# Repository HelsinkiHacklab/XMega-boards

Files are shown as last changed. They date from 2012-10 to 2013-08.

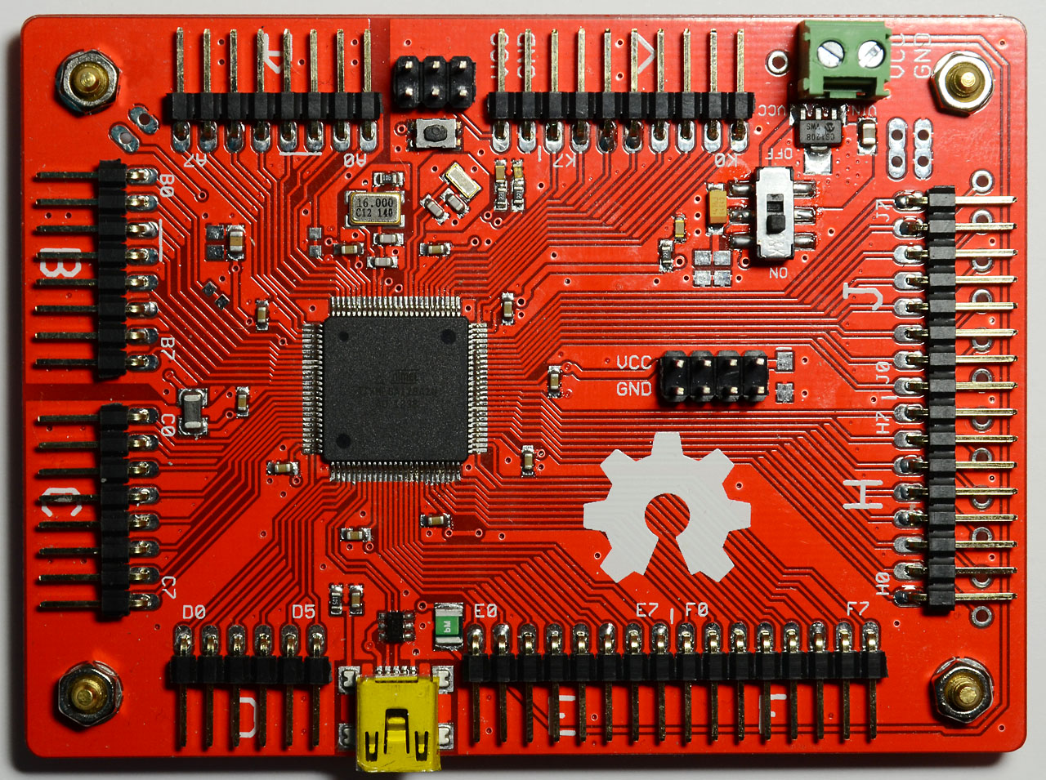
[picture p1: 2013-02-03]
XmegaA1U_v1.jpg

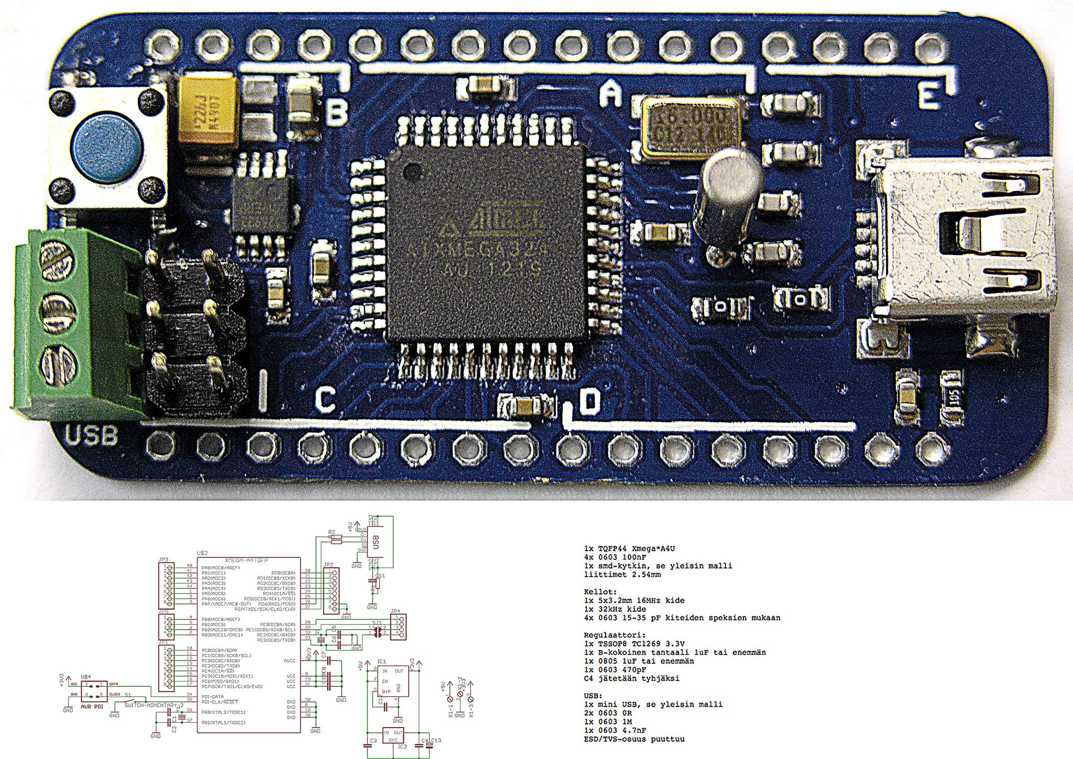
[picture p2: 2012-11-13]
XmegaA4U_v1.jpg

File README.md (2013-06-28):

XMega-boards
============

Breakouts for various XMegas with required supporting hardware

## Boards

  - XmegaA4U_v1: XMEGA A4U, TSSOP-8 regulator (TO-92 as an option), mini USB, 30 i/o pins.
    The first test board, works fine but the regulator used
    is no longer stocked by digikey/mouser. You can still use a TO-92 
    regulator though.
  - XmegaA4U_v2.0: XMEGA A4U, SOT-89 regulator, mini USB, 30 i/o pins.
    A slightly revised edition of v1. USB resistors removed, one LED added and regulator changed.
  - XmegaA4U_v2.1: XMEGA A4U, TSSOP-8 regulator, micro USB, 20 i/o pins.
    A smaller version with fewer pins and a split ground plane. Supports minimal 
    AVCC and AREF filtering. USB connector changed, reset button and 
    separate power connector removed.
  - XmegaA4U_v2.3: XMEGA A4U, SOT-89 regulator, micro USB, 30 i/o pins.
    Version with micro USB, some additional vcc/gnd pins and possibility to 
    add leds to pins E2 and E3.

## Software

For example Arduino IDE (well, XMegaduino) pin definitions for these boards (or at least some of them).

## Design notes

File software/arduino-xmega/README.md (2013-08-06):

# Arduino-XMega patches

1. Get the base software from https://github.com/akafugu/Xmegaduino
2. Under the installation directory in `hardware/xmegaduino/variants` symlink/copy the directories from the variants directory in this repo
3. Under the installation directory in `hardware/xmegaduino/` to `board.txt` add (to end of file) the contents of `add_to_boards.txt`

I (rambo) [updated](https://github.com/rambo/arduino-tiny/tree/attiny1634/avr-gcc) the AVR toolchain but I'm not 100% it's required.

## More detailed instructions

1. Download correct package for your platform from [download page](https://github.com/akafugu/Xmegaduino/downloads) (MacOS, Linux or Windows)
2. Extract the package
3. Get this project by checking it out from GitHub with `git clone https://github.com/HelsinkiHacklab/XMega-boards.git`
4. Copy or link `hhl_xmega32_v1_pdi` from `XMega-boards/software/arduino-xmega/variants/` under `hardware/xmegaduino/variants` in the directory you extracted from package in step 2.
5. Add text from `add_to_boards.txt` in `boards.txt` file in `hardware/xmegaduino`
6. Depending on your platform, the `hardware` directory may be in different places
    * On Windows and Linux package extracts into directory called `arduino`and `hardware` is a subdirectory under it.
    * On MacOS package extracts into Arduino.App application bundle and `hardware` is inside it under `Contents/Resources/Java`. You can either Ctrl-click on Finder and select "Show package contents". On commandline the application bundle shows as a regular directory.
7. If you don't have git (Windows), you can either download the repository as zipfile from repository's front page or use "raw" button to get individual files. If you do latter, remember to create `hhl_xmega32_v1_pdi` directory and put `pins_arduino.h` and `serial_init.cpp` in there.

## TODO

Instructions on how to make Arduino IDE to keep the hex-file (and how to find it) so you can use dfu_programmer in case you have no PDI-capable programmer handy

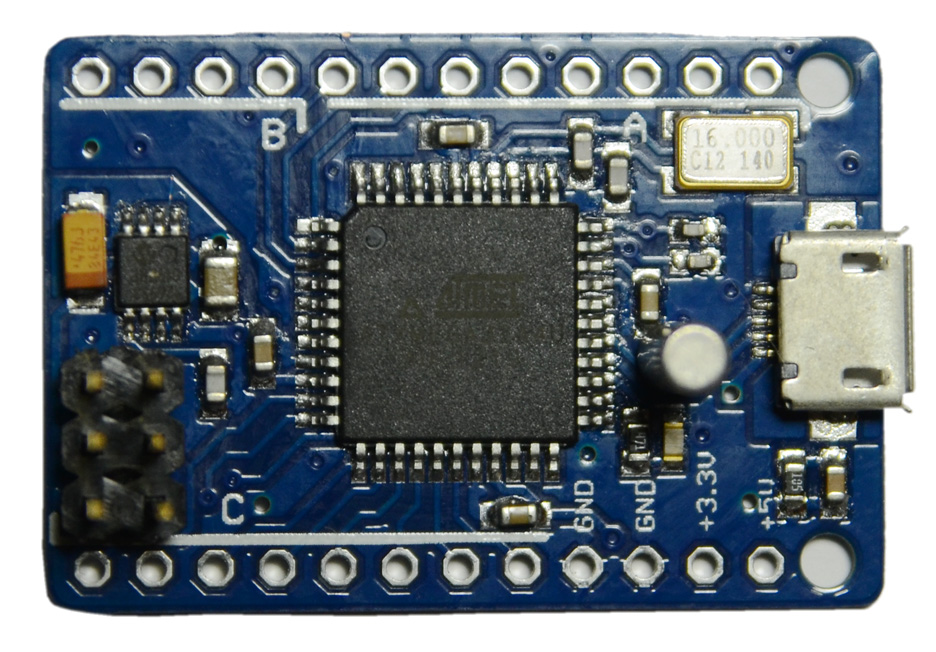
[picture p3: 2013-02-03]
XmegaA4U_v2.1.jpg

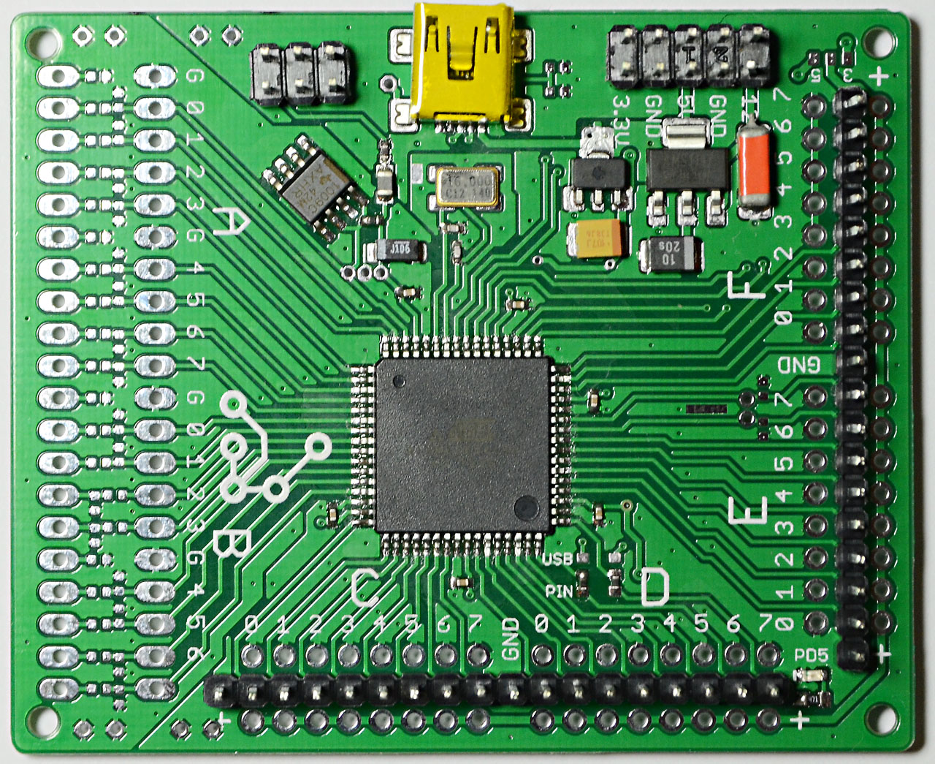
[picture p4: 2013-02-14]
XmegaA3U_v1.jpg

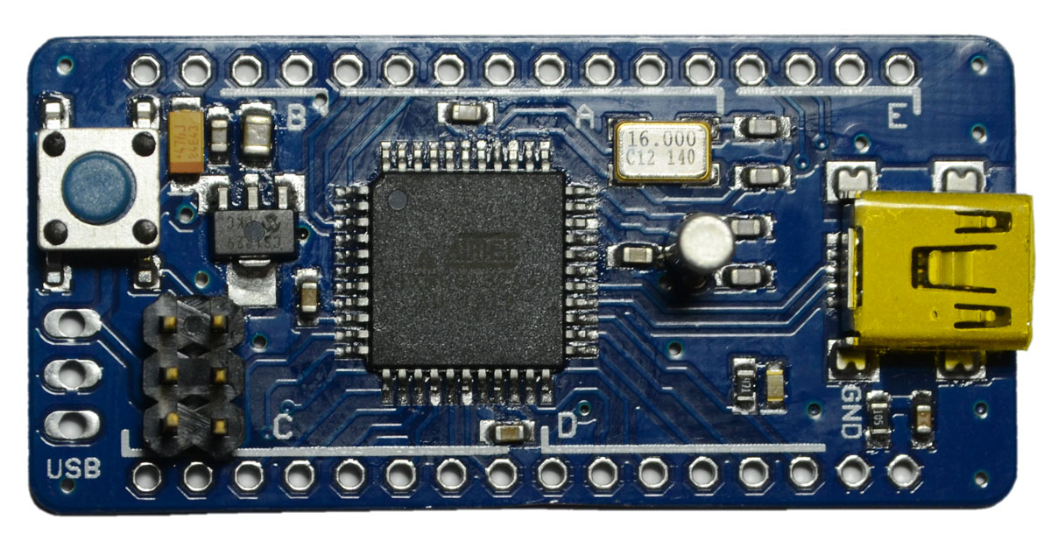
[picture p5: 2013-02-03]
XmegaA4U_v2.0.jpg

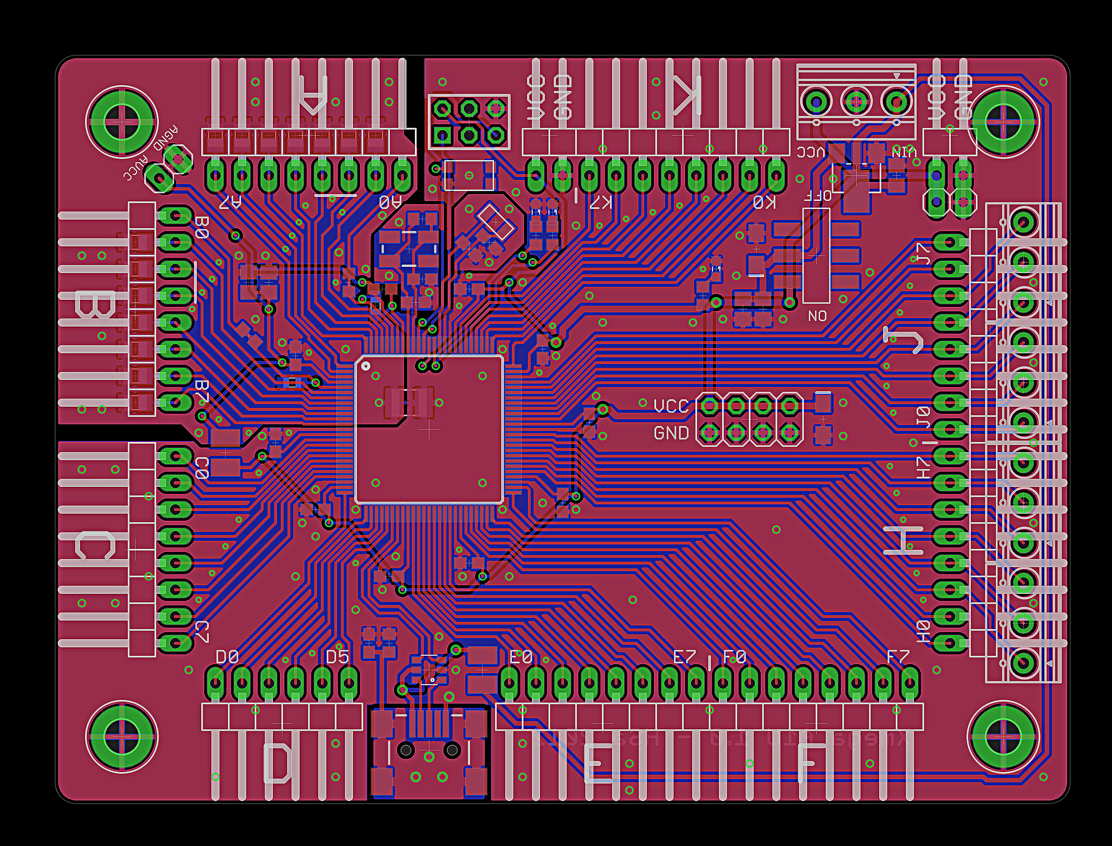
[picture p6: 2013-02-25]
XmegaA1U_v1_art.jpg

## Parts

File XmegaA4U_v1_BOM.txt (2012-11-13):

Kontrolleri Xmega32A4U

Alkuperäisen suunnitelman mukainen komponenttilista:
IC1: Microchip TC1269 3.3V
U$1: Mini USB B /w board guide, se yleisin malli
S1: SMD-painonappi, se yleisin malli 
Y1: 5.0x3.2 mm kide 
Q1: TH 32 kHz kide

Ja ohjearvoja, valmistajien mukaan:
C1-2, C5-6: 0603 konkat kiteiden speksien mukaan
C3: 0805 1 uF tai yli
C4: Jätetään tyhjäksi
C7-10: 0603 100 nF
C11: 0603 4.7 nF (tai jätetään tyhjäksi)
C12: 0603 470 pF tai jätetään tyhjäksi
C13: Tantaali B-case 1 uF tai mielellään yli
R1: 0603 noin 1M (tai 0R tai jätetään tyhjäksi)
R2-3: 0603 0R (tai 10-22R)

Suluissa olevat vaihtoehdot vaihtoehtoisista lähteistä (ei valmistajan suositus). Piirin nurjalla puolella on jumpperit, joilla toisen kellokiteen tilalle saa kaksi io-pinniä. R2 ja R3 toimivat USB:n datan jumppereina.

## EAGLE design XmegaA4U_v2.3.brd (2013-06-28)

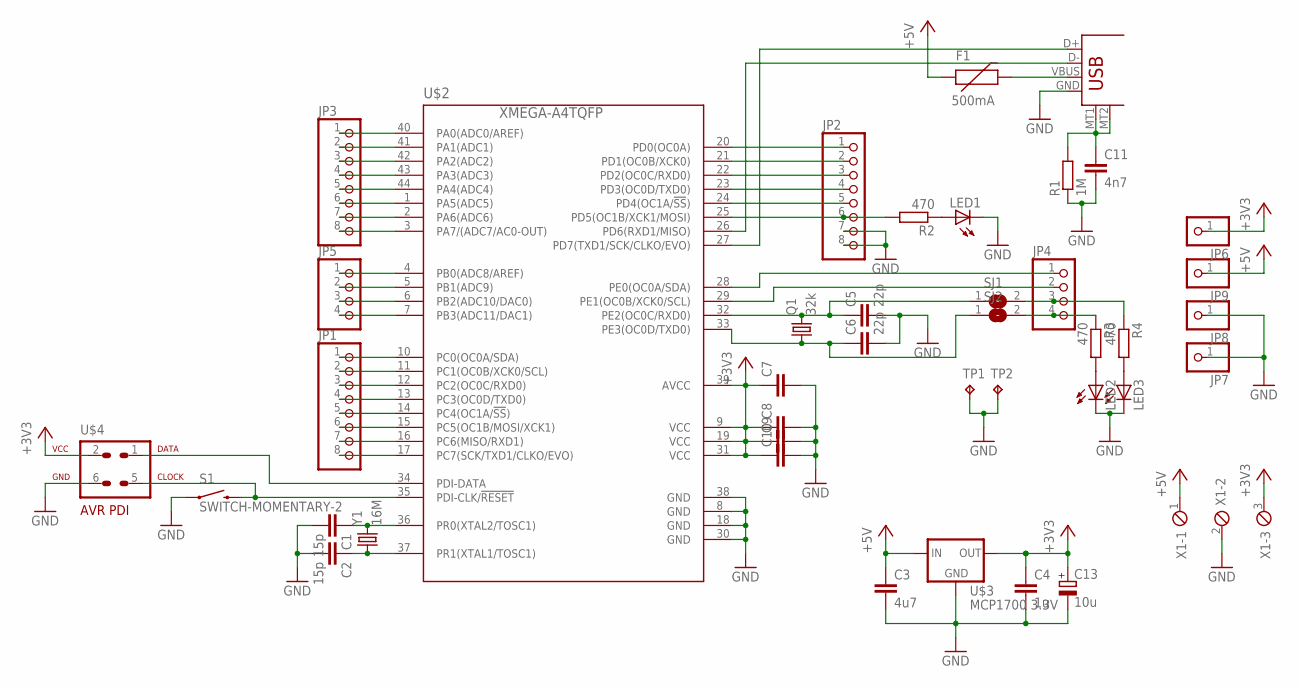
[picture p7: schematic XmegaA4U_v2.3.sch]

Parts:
C1, C2: 15p; C0603
C3: 4u7; C0805
C4: 1u; C0603
C5, C6: 22p; C0603
C7, C8, C9, C10: C-EUC0603; C0603
C11: 4n7; C0603
C13: 10u; SMC_A
F1: 500mA; 0805
JP1, JP2, JP3: PINHD_FIXEDPAD_ROUND-1X8; 1X08_ROUND
JP4, JP5: PINHD_FIXEDPAD_ROUND-1X4; 1X04_ROUND
JP6, JP7, JP8, JP9: PINHD_FIXEDPAD_ROUND-1X1; 1X01_ROUND
LED1, LED2, LED3: LEDCHIP-LED0603; CHIP-LED0603
Q1: 32k; TC26V_1.27
R1: 1M; R0603
R2, R3, R4: 470; R0603
S1: SWITCH-MOMENTARY-2; TACTILE_SWITCH_TALL
SJ1, SJ2: SJ_SMALL; SJ_2S-NO
TP1, TP2: TPTP15R; TP15R
U$2: XMEGA-A4TQFP; TQFP44
U$3: MCP1700 3.3V; SOT89-W
U$4: AVR-PDIVERT; AVR-ISP-6
U$5: USB+SHIELDMICRO; USB-MICROB
X1: MPT3; 3POL254
Y1: 16M; CRYSTAL-SMD-5X3

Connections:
+3V3: C4.1, C7.1, C8.1, C9.1, C10.1, C13.+, JP6.1, U$2.9 (VCC), U$2.19 (VCC), U$2.31 (VCC), U$2.39 (AVCC), U$3.3 (OUT), U$4.2, X1.3
+5V: C3.1, F1.1, JP9.1, U$3.2 (IN), U$3.TAB (IN), X1.1
GND: C1.2, C2.2, C3.2, C4.2, C5.2, C6.2, C7.2, C8.2, C9.2, C10.2, C11.2, C13.-, JP2.7, JP2.8, JP7.1, JP8.1, LED1.C, LED2.C, LED3.C, R1.1, S1.A2 (1), TP1.TP, TP2.TP, U$2.8 (GND), U$2.18 (GND), U$2.30 (GND), U$2.38 (GND), U$3.1 (GND), U$4.6, U$5.GND, X1.2
MTN: C11.1, R1.2, U$5.MT1, U$5.MT2
unnamed: C1.1, U$2.36 (PR0(XTAL2/TOSC1)), Y1.3 (2)
unnamed: C2.1, U$2.37 (PR1(XTAL1/TOSC1)), Y1.1
unnamed: F1.2, U$5.VBUS
unnamed: LED1.A, R2.1
unnamed: JP2.2, U$2.21 (PD1(OC0B/XCK0))
unnamed: JP2.3, U$2.22 (PD2(OC0C/RXD0))
unnamed: JP2.4, U$2.23 (PD3(OC0D/TXD0))
unnamed: JP2.5, U$2.24 (PD4(OC1A/!SS!))
unnamed: LED2.A, R3.2
unnamed: U$2.26 (PD6(RXD1/MISO)), U$5.D-
unnamed: LED3.A, R4.2
unnamed: JP3.2, U$2.41 (PA1(ADC1))
unnamed: JP3.3, U$2.42 (PA2(ADC2))
unnamed: JP3.4, U$2.43 (PA3(ADC3))
unnamed: JP3.5, U$2.44 (PA4(ADC4))
unnamed: JP3.6, U$2.1 (PA5(ADC5))
unnamed: JP3.7, U$2.2 (PA6(ADC6))
unnamed: JP1.2, U$2.11 (PC1(OC0B/XCK0/SCL))
unnamed: JP1.3, U$2.12 (PC2(OC0C/RXD0))
unnamed: JP1.4, U$2.13 (PC3(OC0D/TXD0))
unnamed: JP1.5, U$2.14 (PC4(OC1A/!SS!))
unnamed: JP1.6, U$2.15 (PC5(OC1B/MOSI/XCK1))
unnamed: JP1.7, U$2.16 (PC6(MISO/RXD1))
unnamed: JP5.2, U$2.5 (PB1(ADC9))
unnamed: JP5.3, U$2.6 (PB2(ADC10/DAC0))
unnamed: S1.B2 (2), U$2.35 (PDI-CLK/!RESET), U$4.5
unnamed: U$2.27 (PD7(TXD1/SCK/CLKO/EVO)), U$5.D+
unnamed: U$2.34 (PDI-DATA), U$4.1
XA0: JP3.1, U$2.40 (PA0(ADC0/AREF))
XA7: JP3.8, U$2.3 (PA7/(ADC7/AC0-OUT))
XB0: JP5.1, U$2.4 (PB0(ADC8/AREF))
XB3: JP5.4, U$2.7 (PB3(ADC11/DAC1))
XC0: JP1.1, U$2.10 (PC0(OC0A/SDA))
XC7: JP1.8, U$2.17 (PC7(SCK/TXD1/CLKO/EVO))
XD0: JP2.1, U$2.20 (PD0(OC0A))
XD5: JP2.6, R2.2, U$2.25 (PD5(OC1B/XCK1/MOSI))
XE0: JP4.1, U$2.28 (PE0(OC0A/SDA))
XE1: JP4.2, U$2.29 (PE1(OC0B/XCK0/SCL))
XE2: C5.1, Q1.2, SJ1.1, U$2.32 (PE2(OC0C/RXD0))
XE2S: JP4.3, R4.1, SJ1.2
XE3: C6.1, Q1.1, SJ2.1, U$2.33 (PE3(OC0D/TXD0))
XE3S: JP4.4, R3.1, SJ2.2

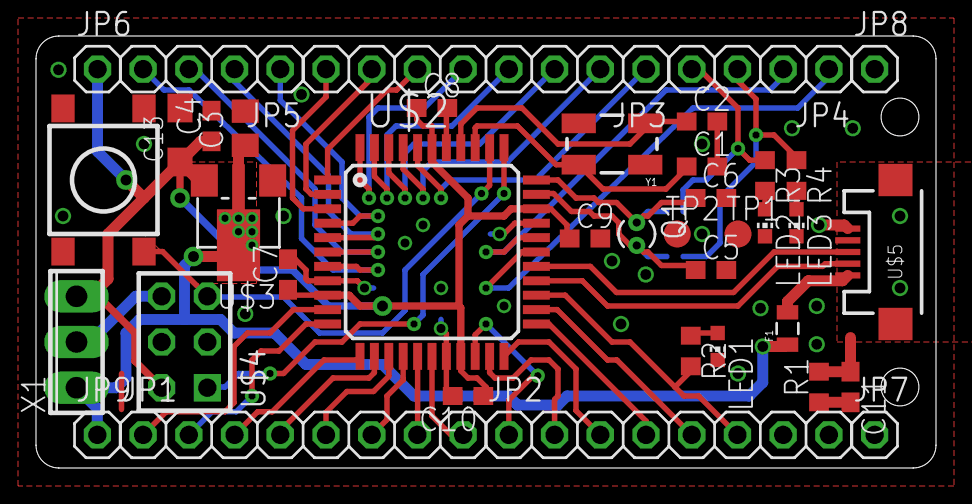
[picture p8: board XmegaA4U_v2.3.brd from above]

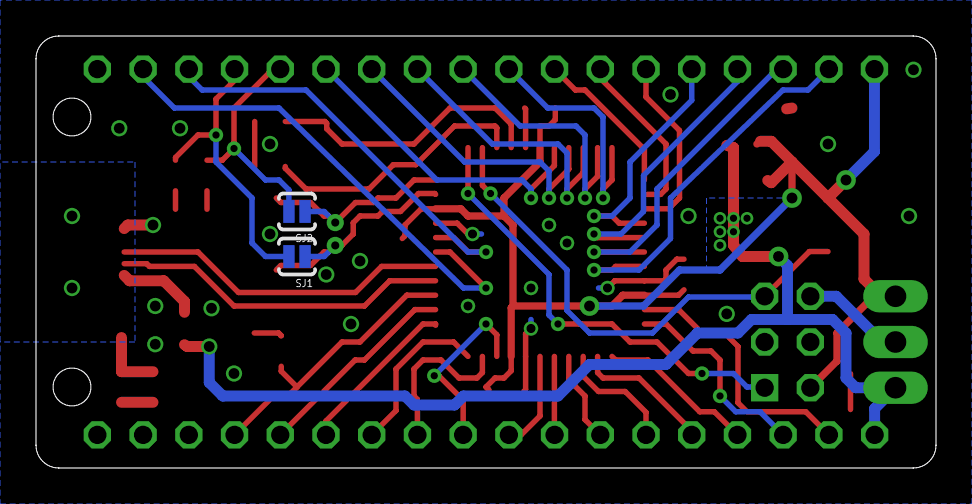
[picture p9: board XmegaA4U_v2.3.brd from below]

Board: 2 copper layers, 50.0 x 24.0 mm, 41 parts (2 on the bottom side), 46 nets.

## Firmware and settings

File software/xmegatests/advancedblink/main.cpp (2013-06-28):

// XMEGA 32AU4 Test 1 - Advanced LED blinking on PD5 with clocks:
//
//  - clkCPU/PER = 2 x external 16 MHz crystal oscillator = 32 MHz 
//  - clkPER4 = 4 x clkPER = 128 MHz hi-res clock
// 	- hi-res clock routed to PD4! Don't leave tangling jumpper wire on this pin, because it will act as an antenna!
//  - timer E0 used as system tick counter
//
// This code is demonstration purposes only, do not use in production code!
//
// References are to Atmel's documents:
//  - [AU] = doc8331.pdf, XMEGA AU Manual
//  - [A4U] = doc8387.pdf, ATxmega*A4U Datasheet
// 

#include <stddef.h>					// offsetof(…)

#include <avr/eeprom.h>
#include <avr/pgmspace.h>
#include <avr/io.h> 				// /usr/local/CrossPack-AVR/avr/include/avr/iox32a4u.h
#include <avr/cpufunc.h> 
#include <avr/interrupt.h>


// If something goes wrong, halt and blink the PD5 LED, frequency somewhat related to error parameter
void HALT(uint8_t error = 0) {
	cli();
	PORTD.DIRSET = 0b00100000; 		
	while (true) {	
		PORTD.OUTTGL = 0b00100000; 	
		for (uint32_t i = 0; i < error*2222ul; i++) { GPIO0 += GPIO1; } 
		PORTD.OUTTGL = 0b00100000; 	
		for (uint32_t i = 0; i < 400000; i++) { GPIO0 += GPIO1; } 
	}
}

// Unhandled interrupts
ISR(BADISR_vect, ISR_BLOCK) { HALT(255); };


// Port E, Counter 0, works as System Tick Counter
volatile uint32_t tick_counter_63to32 = 0;     // Incremented every ~134 second
volatile uint16_t tick_counter_31to16 = 0;     // Incremented ~488 times per second
ISR(TCE0_OVF_vect, ISR_BLOCK) {          		// interrupt service routine that wraps a user defined function supplied by attachInterrupt
	cli();
  		++tick_counter_31to16;
		if (tick_counter_31to16 == 0) { ++tick_counter_63to32;	}
	sei();
}

inline uint16_t getTickCount16() {
  cli();
  	uint16_t   ticks = TCE0.CNT;            // (1a) Read HW timer
  sei();

  return ticks;
}

inline uint32_t getTickCount32() {
  cli();
  
  	uint16_t   timer = TCE0.CNT;            // (1a) Read HW timer
  	if (TCE0.INTFLAGS & 0b1) { 				// INTFLAGS[0] – OVFIF: Overflow/Underflow Interrupt Flag
  		// Handle it straight here, instead of the interrupt handler
    	TCE0.INTFLAGS |= 0b1;                // Clear the pending interrupt
    	timer = TCE0.CNT;                   // (1b) Overflow occurred concurrently, read timer again to get new value after overflow
	  	++tick_counter_31to16;				  
		if (tick_counter_31to16 == 0) { ++tick_counter_63to32;	}
  	}
  
  	uint32_t ticks = uint32_t(tick_counter_31to16) << 16 | timer;    // (2) Read volatile overflow counter
  
  sei();

  return ticks;
}

inline uint64_t getTickCount64() {
  cli();
  
  	uint16_t   timer = TCE0.CNT;            // (1a) Read HW timer
  	if (TCE0.INTFLAGS & 0b1) { 				// INTFLAGS[0] – OVFIF: Overflow/Underflow Interrupt Flag
  		// Handle it straight here, instead of the interrupt handler
    	TCE0.INTFLAGS |= 0b1;                // Clear the pending interrupt
    	timer = TCE0.CNT;                   // (1b) Overflow occurred concurrently, read timer again to get new value after overflow
	  	++tick_counter_31to16;
		if (tick_counter_31to16 == 0) { ++tick_counter_63to32;	}
  	}
  
  	uint64_t ticks = uint64_t(tick_counter_63to32) << 32 | uint32_t(tick_counter_31to16) << 16 | timer;    // (2) Read volatile overflow counter
  
  sei();

  return ticks;
}

// Assumed clkCPU = 32 MHz
enum {
	TicksInMicrosecond 		= 32ull,
	TicksInMillisecond 		= TicksInMicrosecond*1000,
	TicksInSecond 			= TicksInMillisecond*1000,
	TicksInMinute 			= TicksInSecond*60,
	TicksInHour 			= TicksInMinute*60,
	TicksInDay	 			= TicksInHour*24,
};

// Busyloop delay functions
void delayTicks(uint64_t ticks) {
	uint64_t endtick = getTickCount64() + ticks;
	
	while (endtick > getTickCount64()) { }
}

void delayMicroseconds(uint64_t us) {
	delayTicks(us*TicksInMicrosecond);
}

void delayMilliseconds(uint64_t ms) {
	delayTicks(ms*TicksInMillisecond);
}

void delaySeconds(uint64_t s) {
	delayTicks(s*TicksInSecond);
}




uint8_t ReadCalibrationByte(uint16_t index) {
	uint8_t result;

	// Load the NVM Command register to read the calibration row.
	NVM.CMD = NVM_CMD_READ_CALIB_ROW_gc;
	result = pgm_read_byte(index);
	
	// Clean up NVM Command register.
	NVM.CMD = NVM_CMD_NO_OPERATION_gc;
	
	return result;
} 

// Sets clkCPU/PER system clock and clkPER4 hi-res
//  - the standard 32 MHz with 128 MHz hi-res = setClockExternal16MHzHiRes(8, 1)
//  - overclocking 68 MHz with 272 MHz hi-res = setClockExternal16MHzHiRes(17, 1) <- not stable, but some chips might work for testing purposes 
void setClockExternal16MHzHiRes(uint8_t multiplier, uint16_t divider) {

	uint8_t pll = 0;
	
	if (1 <= multiplier && multiplier <= 31 ) {
		pll = multiplier;
	} else HALT();
	
	uint8_t prescaler = 0;
		
	switch (divider) {
		case   1 :	prescaler = 0b00000;		break;
		case   2 :	prescaler = 0b00001;		break;
		case   4 :	prescaler = 0b00011;		break;
		case   8 :	prescaler = 0b00101;		break;
		case  16 :	prescaler = 0b00111;		break;
		case  32 :	prescaler = 0b01001;		break;
		case  64 :	prescaler = 0b01011;		break;
		case 128 :	prescaler = 0b01101;		break;
		case 256 :	prescaler = 0b01111;		break;
		case 512 :	prescaler = 0b10001;		break;
		default : 	HALT();					break;	
	}

	OSC.XOSCCTRL = 0b11 << 6 | 0b1011; // Enable 16MHz XTAL with 16K CLK start-up time

	OSC.CTRL |= 0b01000; // Enable External Oscillator
	while((OSC.STATUS & 0b01000) == 0) { } // Wait External Oscillator to stabilize

	OSC.PLLCTRL = 0b11 << 6 | pll; // Select External clock source with 1x..31x PLL
	OSC.CTRL |= 0b10000; // Enable PLL
	while((OSC.STATUS & 0b10000) == 0) { } // Wait PLL to stabilize
	
	uint8_t psctrl = prescaler << 2 | 0b11; // clkPER4 /2 = clkPER2 /2 = clkPER/CPU, protected by CCP!
	CCP = 0xD8; // Unlock Configuration Change Protection
	CLK.PSCTRL = psctrl;
	if (CLK.PSCTRL != psctrl) HALT();		// Error!

	uint8_t ctrl = 0b100; // Select PLL to System Clock
	CCP = 0xD8; // Unlock Configuration Change Protection
	CLK.CTRL = ctrl;
	if (CLK.CTRL != ctrl) HALT();			// Error!

}



int main() {
	cli();

		// Set system clock	
		setClockExternal16MHzHiRes( 8, 1);

		// Timer Counter 0 in port E is used as system cycle counter
		TCE0.CTRLA = 0b0000;													// Stop timer now
		TCE0.CTRLB = 0b0000 << 4 | 0b000 ;										// Normal counter, no output
		TCE0.CTRLD = 0b000 << 5 | 0b0 << 4 | 0b0000;							// No event action, no event source
		TCE0.CTRLE = 0b00;														// Normal counter type 0
		TCE0.INTCTRLA = 0b00 << 2 | 0b11;										// Timer Overflow Interrupt at High-level, no error handling, TODO
		TCE0.INTCTRLB = 0b00 << 6 | 0b00 << 4 | 0b00 << 2 | 0b00;				// No compare nor capture
		TCE0.CNT = 0;															// Clear counter
		TCE0.CTRLA = 0b0001;													// = DIV1, Prescaler: Clk  => Start counter

		// Interrupts and Programmable Multilevel Interrupt Controller
		PMIC.INTPRI = 0; 														// Reset round-robin
		PMIC.CTRL = 0b1 << 7 | 0b0 << 6 | 0b111;   								// Round-robin Scheduling Enabled, Vectors in application flash, section, all levels enabled	
	
	sei();


	// clkPER4 out to PD4
	PORTCFG.CLKEVOUT = 0b1 << 7 | 0b10 << 2 | 0b10;
	PORTD.DIRSET =	0b00010000;

	
	PORTD.DIRSET = 0b00100000; 		// PD5 as output for the LED

	 
	while (true) {	
		
		// Toggle LED
		PORTD.OUTTGL = 0b00100000; 	// Toggle PD5

		delaySeconds(1);

	}

	return -1; // This should never happen	
}

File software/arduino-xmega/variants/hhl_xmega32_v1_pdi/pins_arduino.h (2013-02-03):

/*
  pins_arduino.h - Pin definition functions for Arduino
  Part of Arduino - http://www.arduino.cc/

  Copyright (c) 2007 David A. Mellis

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
*/

/**
 * Pin map for https://github.com/HelsinkiHacklab/XMega-boards/blob/master/XmegaA4U_v1.brd
 * 
 *

            USB
    0   PE0     GND
    1   PE1     GND
    2   PE2     PD5   29
    3   PE3     PD4   28
    4   PA0     PD3   27
    5   PA1     PD2   26
    6   PA2     PD1   25
    7   PA3     PD0   24
    8   PA4     PC7   23
    9   PA5     PC6   22
   10   PA6     PC5   21
   11   PA7     PC4   20
   12   PB0     PC3   19
   13   PB1     PC2   18
   14   PB2     PC1   17
   15   PB3     PC0   16

Port A&B is ADC, ANALOG0 -> PB3 ANALOG7 -> PA11

USARTS

  Serial = 19 (RX) & 20 (TX)
  Serial1 = 23 (RX) & 24 (TX)
  Serial2 = 27 (RX) & 28 (TX)
  Serial3 = 3 (RX) & 4 (TX)

*/


#ifndef Pins_Arduino_h
#define Pins_Arduino_h

#include <avr/pgmspace.h>

#define USE_RTC // Use RTC for millis etc.


#define REPEAT8(x) x, x, x, x, x, x, x, x
#define BV0TO7 _BV(0), _BV(1), _BV(2), _BV(3), _BV(4), _BV(5), _BV(6), _BV(7)
#define BV7TO0 _BV(7), _BV(6), _BV(5), _BV(4), _BV(3), _BV(2), _BV(1), _BV(0)

#define NUM_DIGITAL_PINS            30
#define NUM_ANALOG_INPUTS           8
// WTF
#define EXTERNAL_NUM_INTERRUPTS     30 // PORTA to PORTE 3

#define analogInputToDigitalPin(p)  ((p < 12) ? (p) + 5 : -1)
#define digitalPinHasPWM(p)         (((p) >= 0 && (p) <= 3) || ((p) >= 16 && (p)<= 21) || ((p) >= 24 && (p)<= 29))


// TODO: Map correctly
static const uint8_t SS    = 6;
static const uint8_t MOSI  = 11;
static const uint8_t MISO  = 12;
static const uint8_t SCK   = 13;

// TODO: Map correctly
static const uint8_t SDA = 2;
static const uint8_t SCL = 3;
static const uint8_t LED_BUILTIN = 13;

// TODO: Map correctly
#define SPI_PORT	SPID

static const uint8_t A0 = 5;
static const uint8_t A1 = 6;
static const uint8_t A2 = 7;
static const uint8_t A3 = 8;
static const uint8_t A4 = 9;
static const uint8_t A5 = 10;
static const uint8_t A6 = 11;
static const uint8_t A7 = 12;
static const uint8_t A8 = 14;
static const uint8_t A9 = 14;
static const uint8_t A10 = 15;
static const uint8_t A11 = 16;

#define Wire xmWireC
#define Wire1 xmWireE


// TODO: Fix these mapping macros
/*
#define digitalPinToPCICR(p)    (((p) >= 0 && (p) <= 21) ? (&PCICR) : ((uint8_t *)0))
#define digitalPinToPCICRbit(p) (((p) <= 7) ? 2 : (((p) <= 13) ? 0 : 1))
#define digitalPinToPCMSK(p)    (((p) <= 7) ? (&PCMSK2) : (((p) <= 13) ? (&PCMSK0) : (((p) <= 21) ? (&PCMSK1) : ((uint8_t *)0))))
#define digitalPinToPCMSKbit(p) (((p) <= 7) ? (p) : (((p) <= 13) ? ((p) - 8) : ((p) - 14)))
*/

#ifdef ARDUINO_MAIN

// these arrays map port names (e.g. port B) to the
// appropriate addresses for various functions (e.g. reading
// and writing)
const uint16_t PROGMEM port_to_PGM[] = {
	NOT_A_PORT,
	(uint16_t) &PORTA,
	(uint16_t) &PORTB,
	(uint16_t) &PORTC,
	(uint16_t) &PORTD,
	(uint16_t) &PORTE,
};

const uint8_t PROGMEM digital_pin_to_port_PGM[] = {
    PE,
    PE,
    PE,
    PE,
    PA,
    PA,
    PA,
    PA,
    PA,
    PA,
    PA,
    PA,
    PB,
    PB,
    PB,
    PB,
    PC,
    PC,
    PC,
    PC,
    PC,
    PC,
    PC,
    PC,
    PD,
    PD,
    PD,
    PD,
    PD,
    PD,
};

const uint8_t PROGMEM digital_pin_to_bit_mask_PGM[] = {
		// PIN IN PORT		
		// -------------------------------------------		
		_BV( 0 ), 
		_BV( 1 ),
		_BV( 2 ),
		_BV( 3 ),
		_BV( 0 ),
		_BV( 1 ),
		_BV( 2 ),
		_BV( 3 ),
		_BV( 4 ), 
		_BV( 5 ),
		_BV( 6 ),
		_BV( 7 ),
		_BV( 0 ),
		_BV( 1 ),
		_BV( 2 ), 
		_BV( 3 ),
		_BV( 0 ),
		_BV( 1 ),
		_BV( 2 ),
		_BV( 3 ),
		_BV( 4 ),
		_BV( 5 ), 
		_BV( 6 ), 
		_BV( 7 ),
		_BV( 0 ),
		_BV( 1 ),
		_BV( 2 ),
		_BV( 3 ),
		_BV( 4 ),
		_BV( 5 ),
};

const uint8_t PROGMEM digital_pin_to_timer_PGM[] = {
	// TIMERS		
	// -------------------------------------------		
	TIMER_E0A   	, // 0
	TIMER_E0B   	, 
	TIMER_E0C   	, 
	TIMER_E0D   	,   // 3
	NOT_ON_TIMER	, 
	NOT_ON_TIMER	, 
	NOT_ON_TIMER	, 
	NOT_ON_TIMER	, 
	NOT_ON_TIMER	, 
	NOT_ON_TIMER	, 
	NOT_ON_TIMER	, 
	NOT_ON_TIMER	, 
	NOT_ON_TIMER	, 
	NOT_ON_TIMER	, 
	NOT_ON_TIMER	, 
	NOT_ON_TIMER	, 
	TIMER_C0A   	,  // 16
	TIMER_C0B   	, 
	TIMER_C0C   	, 
	TIMER_C0D   	, 
	TIMER_C1A   	, 
	TIMER_C1B   	, 
	NOT_ON_TIMER	,  // 22
	NOT_ON_TIMER	, 
	TIMER_D0A       ,  // 24
	TIMER_D0B       , 
	TIMER_D0C       , 
	TIMER_D0D       , 
	TIMER_D1A       , 
	TIMER_D1B       , // 29
};

const TC0_t* PROGMEM timer_to_tc0_PGM[] = {
	NULL,

	&TCC0,
	&TCC0,
	&TCC0,
	&TCC0,
	NULL,
	NULL,

	&TCD0,
	&TCD0,
	&TCD0,
	&TCD0,
	NULL,
	NULL,

	&TCE0,
	&TCE0,
	&TCE0,
	&TCE0,
	NULL,
	NULL,
	};

const TC1_t* PROGMEM timer_to_tc1_PGM[] = {
	NULL,

	NULL,
	NULL,
	NULL,
	NULL,
	&TCC1,
	&TCC1,

	NULL,
	NULL,
	NULL,
	NULL,
	&TCD1,
	&TCD1,

	NULL,
	NULL,
	NULL,
	NULL,
	NULL,
	NULL,
};


const uint8_t PROGMEM timer_to_channel_PGM[] = {
	NOT_ON_TIMER,

    0,
    1,
    2,
    3,
    0,
    1,

    0,
    1,
    2,
    3,
    0,
    1,

    0,
    1,
    2,
    3,
    0,
    1,
};
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

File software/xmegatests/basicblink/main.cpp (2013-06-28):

// XMEGA 32AU4 Test 0 - Basic LED blinking on PD5 with default internal 2 MHz oscillator
//
// This code is demonstration purposes only, do not use in production code!
//
// References are to Atmel's documents:
//  - [AU] = doc8331.pdf, XMEGA AU Manual
//  - [A4U] = doc8387.pdf, ATxmega*A4U Datasheet
// 

#include <avr/io.h> 				// .../avr/include/avr/iox32a4u.h


int main() {
	
	// Set PD5 as output, it has LED in the default board 
	// - there are different registers for setting=SET, clearing=CLR and toggling=TGL for only some bits in direction=DIR and output=OUT registers
	// - for more info see [AU 13.13]
	PORTD.DIRSET = 0b00100000; 		


	// Stay in infinite loop
	while (true) {	
			
		// Toggle PD5 pin	
		PORTD.OUTTGL = 0b00100000; 	
		
		// Approximate 1 second delay by reading and writing the general purpose I/O register so that compiler can't optimize it away
		for (uint32_t i = 0; i < 222222; i++) { GPIO0 += GPIO1; } 
	}

	return -1; // This should never happen	
}

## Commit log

2012-10-31 the files and BOM list exactly as I got them from Heikki, so comments in finnish etc
    [Xmega.brd, Xmega.sch]
2012-11-04 Link to an image of the board
2012-11-13 renamed to immediately indicate correct chip
    [Xmega32A4U.brd, Xmega32A4U.sch]
2012-11-13 high-rez photo of the board for soldering reference with schematic and bom (notes in finnish, sorry about that)
2013-01-28 Added version 2 of the A4U breakout (created Nov 2012)
    [XmegaA4U_v2.0.brd, XmegaA4U_v2.0.sch]
2013-01-28 Added version 2.1 of the A4U breakout (a bit smaller, fewer pins broken out, created Nov 2012)
    [XmegaA4U_v2.1.brd, XmegaA4U_v2.1.sch]
2013-01-28 Renamed the original A4U breakout files, removed some unnecessary silkscreen texts
    [XmegaA4U_v1.brd, XmegaA4U_v1.sch]
2013-02-03 started writing pin mappings
2013-02-03 pin mappings
2013-02-03 typo fix, moar mappings
    [pins_arduino.h]
2013-02-03 typo fixes in mappings
    [pins_arduino.h]
2013-02-03 this probably is the correct way to map channel with the value returned from digital_pin_to_timer_PGM
    [pins_arduino.h]
2013-02-03 pin numbers start from 0
2013-02-03 Update software/arduino-xmega/README.md
    URL for update instructions just in case it was needed.
2013-02-03 Added photos of the three latest boards
2013-02-03 Let's not include the memory size in the board names.
2013-02-03 The led option was already in 2.0
2013-05-03 Version 2.3 added
    [XmegaA4U_v2.3.brd, XmegaA4U_v2.3.sch]
2013-05-14 More small typo fixes
    [main.cpp]
2013-06-28 note the pin numbers for the serial ports

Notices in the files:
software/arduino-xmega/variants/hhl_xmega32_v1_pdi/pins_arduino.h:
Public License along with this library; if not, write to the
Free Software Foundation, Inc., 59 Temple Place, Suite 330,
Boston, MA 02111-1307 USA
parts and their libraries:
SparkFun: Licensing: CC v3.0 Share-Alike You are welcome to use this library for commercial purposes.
